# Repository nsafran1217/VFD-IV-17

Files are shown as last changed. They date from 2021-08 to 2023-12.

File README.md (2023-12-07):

# VFD-IV-17
This repository contains an Arduino Library and board design for a 4-tube IV-17 board. These boards are chainable.

Requires a 5V, 2.4V, and 25V power supply.

This board has found a permanent home in my Nixie Weather Clock: https://nsafran.com/nixie-and-vfd-weather-clock.html

Some more info on the use of the boards is on my website: https://nsafran.com/iv17-vfd-board.html

The vfddesigner folder is a quick and dirty c# application to help create the bytes to send for each digit. The exe is in vfddesigner/bin/Debug.





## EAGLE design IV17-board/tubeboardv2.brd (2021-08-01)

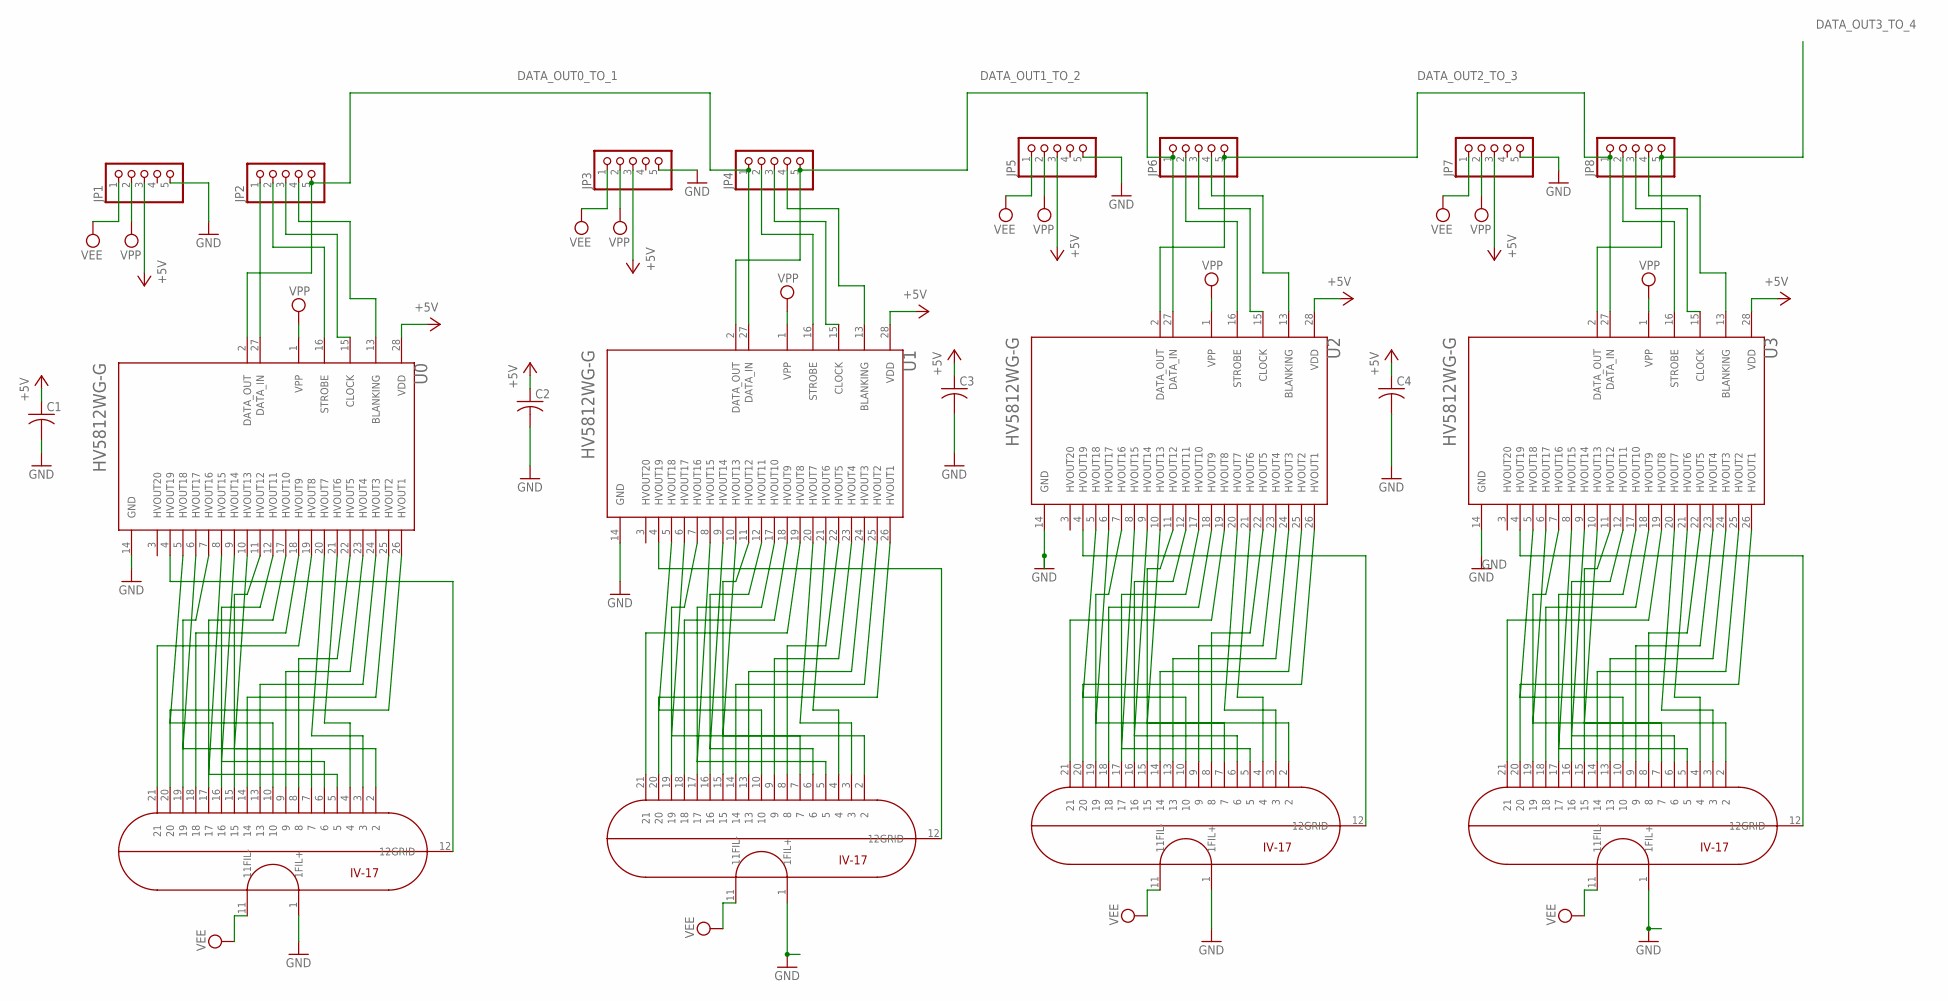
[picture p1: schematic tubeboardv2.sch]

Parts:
C1, C2, C3, C4: C-USC0805; C0805
IV0, IV1, IV2, IV3: IV17; NIXIE-22
JP1, JP2, JP3, JP4, JP5, JP6, JP7, JP8: PINHD-1X5; 1X05
U0, U1, U2, U3: MICROCHIP_HV5812WG-GMICROCHIP_HV5812WG-G_0_0; MICROCHIP_HV5812WG-G_0

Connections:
+5V: C1.1, C2.1, C3.1, C4.1, JP1.3, JP3.3, JP5.3, JP7.3, U0.28 (VDD), U1.28 (VDD), U2.28 (VDD), U3.28 (VDD)
BLANK: JP2.4, JP4.4, JP6.4, JP8.4, U0.13 (BLANKING), U1.13 (BLANKING), U2.13 (BLANKING), U3.13 (BLANKING)
CLOCK: JP2.3, JP4.3, JP6.3, JP8.3, U0.15 (CLOCK), U1.15 (CLOCK), U2.15 (CLOCK), U3.15 (CLOCK)
DATA_IN: JP2.1, U0.27 (DATA_IN)
DATA_OUT0_TO_1: JP2.5, JP4.1, U0.2 (DATA_OUT), U1.27 (DATA_IN)
DATA_OUT1_TO_2: JP4.5, JP6.1, U1.2 (DATA_OUT), U2.27 (DATA_IN)
DATA_OUT2_TO_3: JP6.5, JP8.1, U2.2 (DATA_OUT), U3.27 (DATA_IN)
DATA_OUT3_TO_4: JP8.5, U3.2 (DATA_OUT)
GND: C1.2, C2.2, C3.2, C4.2, IV0.1 (1FIL+), IV1.1 (1FIL+), IV2.1 (1FIL+), IV3.1 (1FIL+), JP1.5, JP3.5, JP5.5, JP7.5, U0.14 (GND), U1.14 (GND), U2.14 (GND), U3.14 (GND)
unnamed: IV0.20, U0.26 (HVOUT1)
unnamed: IV0.14, U0.25 (HVOUT2)
unnamed: IV0.13, U0.24 (HVOUT3)
unnamed: IV0.9, U0.23 (HVOUT4)
unnamed: IV0.8, U0.22 (HVOUT5)
unnamed: IV0.4, U0.21 (HVOUT6)
unnamed: IV0.3, U0.20 (HVOUT7)
unnamed: IV0.21, U0.19 (HVOUT8)
unnamed: IV0.18, U0.18 (HVOUT9)
unnamed: IV0.17, U0.17 (HVOUT10)
unnamed: IV0.16, U0.12 (HVOUT11)
unnamed: IV0.15, U0.11 (HVOUT12)
unnamed: IV0.7, U0.10 (HVOUT13)
unnamed: IV0.6, U0.9 (HVOUT14)
unnamed: IV0.5, U0.8 (HVOUT15)
unnamed: IV0.19, U0.7 (HVOUT16)
unnamed: IV0.2, U0.6 (HVOUT17)
unnamed: IV0.10, U0.5 (HVOUT18)
unnamed: IV0.12 (12GRID), U0.4 (HVOUT19)
unnamed: IV1.20, U1.26 (HVOUT1)
unnamed: IV1.14, U1.25 (HVOUT2)
unnamed: IV1.13, U1.24 (HVOUT3)
unnamed: IV1.9, U1.23 (HVOUT4)
unnamed: IV1.8, U1.22 (HVOUT5)
unnamed: IV1.4, U1.21 (HVOUT6)
unnamed: IV1.3, U1.20 (HVOUT7)
unnamed: IV1.21, U1.19 (HVOUT8)
unnamed: IV1.18, U1.18 (HVOUT9)
unnamed: IV1.17, U1.17 (HVOUT10)
unnamed: IV1.16, U1.12 (HVOUT11)
unnamed: IV1.15, U1.11 (HVOUT12)
unnamed: IV1.7, U1.10 (HVOUT13)
unnamed: IV1.6, U1.9 (HVOUT14)
unnamed: IV1.5, U1.8 (HVOUT15)
unnamed: IV1.19, U1.7 (HVOUT16)
unnamed: IV1.2, U1.6 (HVOUT17)
unnamed: IV1.10, U1.5 (HVOUT18)
unnamed: IV1.12 (12GRID), U1.4 (HVOUT19)
unnamed: IV2.20, U2.26 (HVOUT1)
unnamed: IV2.14, U2.25 (HVOUT2)
unnamed: IV2.13, U2.24 (HVOUT3)
unnamed: IV2.9, U2.23 (HVOUT4)
unnamed: IV2.8, U2.22 (HVOUT5)
unnamed: IV2.4, U2.21 (HVOUT6)
unnamed: IV2.3, U2.20 (HVOUT7)
unnamed: IV2.21, U2.19 (HVOUT8)
unnamed: IV2.18, U2.18 (HVOUT9)
unnamed: IV2.17, U2.17 (HVOUT10)
unnamed: IV2.16, U2.12 (HVOUT11)
unnamed: IV2.15, U2.11 (HVOUT12)
unnamed: IV2.7, U2.10 (HVOUT13)
unnamed: IV2.6, U2.9 (HVOUT14)
unnamed: IV2.5, U2.8 (HVOUT15)
unnamed: IV2.19, U2.7 (HVOUT16)
unnamed: IV2.2, U2.6 (HVOUT17)
unnamed: IV2.10, U2.5 (HVOUT18)
unnamed: IV2.12 (12GRID), U2.4 (HVOUT19)
unnamed: IV3.20, U3.26 (HVOUT1)
unnamed: IV3.14, U3.25 (HVOUT2)
unnamed: IV3.13, U3.24 (HVOUT3)
unnamed: IV3.9, U3.23 (HVOUT4)
unnamed: IV3.8, U3.22 (HVOUT5)
unnamed: IV3.4, U3.21 (HVOUT6)
unnamed: IV3.3, U3.20 (HVOUT7)
unnamed: IV3.21, U3.19 (HVOUT8)
unnamed: IV3.18, U3.18 (HVOUT9)
unnamed: IV3.17, U3.17 (HVOUT10)
unnamed: IV3.16, U3.12 (HVOUT11)
unnamed: IV3.15, U3.11 (HVOUT12)
unnamed: IV3.7, U3.10 (HVOUT13)
unnamed: IV3.6, U3.9 (HVOUT14)
unnamed: IV3.5, U3.8 (HVOUT15)
unnamed: IV3.19, U3.7 (HVOUT16)
unnamed: IV3.2, U3.6 (HVOUT17)
unnamed: IV3.10, U3.5 (HVOUT18)
unnamed: IV3.12 (12GRID), U3.4 (HVOUT19)
STROBE: JP2.2, JP4.2, JP6.2, JP8.2, U0.16 (STROBE), U1.16 (STROBE), U2.16 (STROBE), U3.16 (STROBE)
VEE: IV0.11 (11FIL-), IV1.11 (11FIL-), IV2.11 (11FIL-), IV3.11 (11FIL-), JP1.1, JP3.1, JP5.1, JP7.1
VPP: JP1.2, JP3.2, JP5.2, JP7.2, U0.1 (VPP), U1.1 (VPP), U2.1 (VPP), U3.1 (VPP)

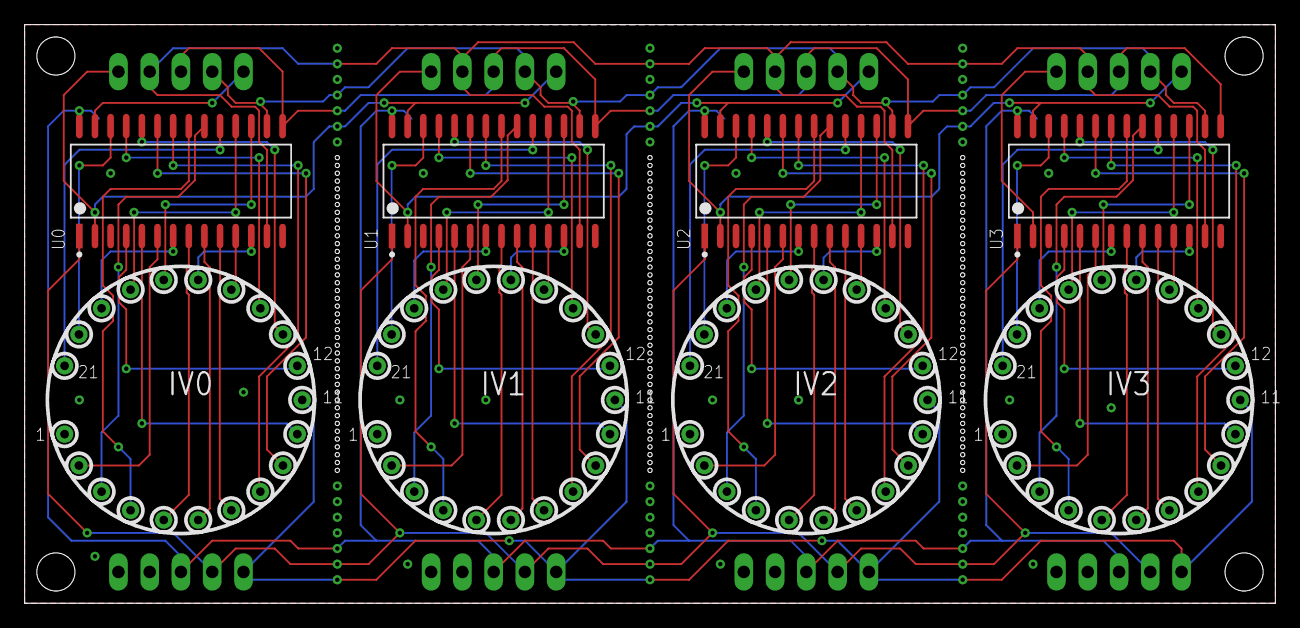
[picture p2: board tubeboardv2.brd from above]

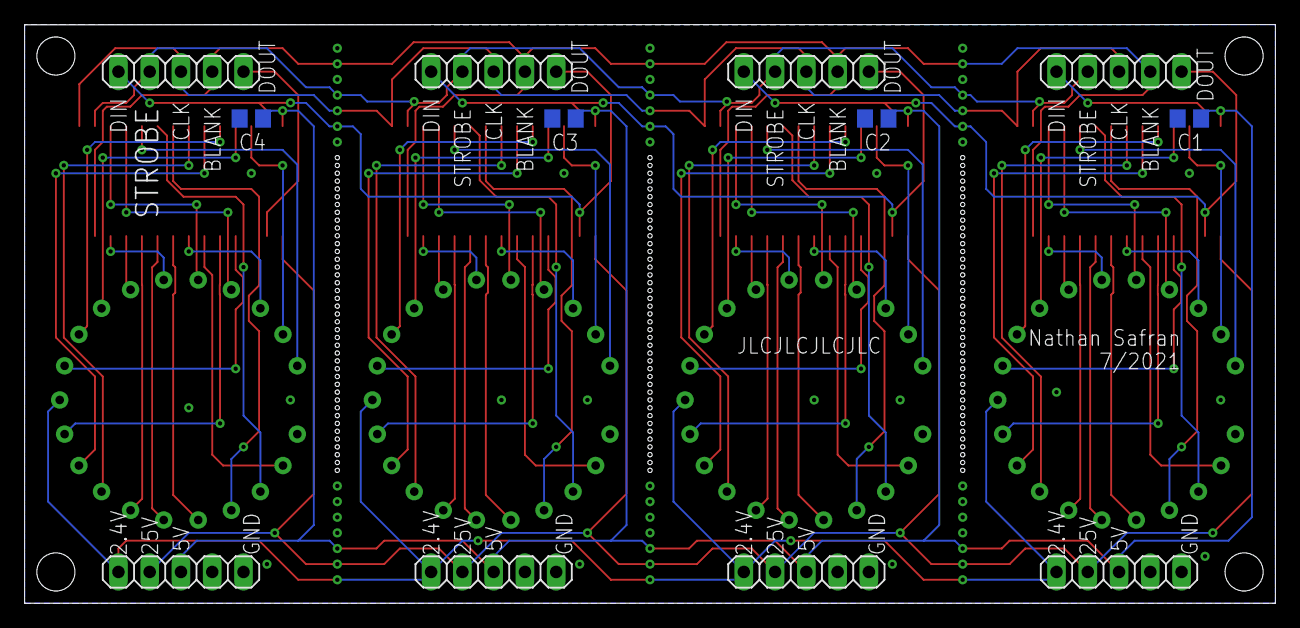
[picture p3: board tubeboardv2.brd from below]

Board: 2 copper layers, 101.6 x 47.0 mm, 20 parts (12 on the bottom side), 88 nets.

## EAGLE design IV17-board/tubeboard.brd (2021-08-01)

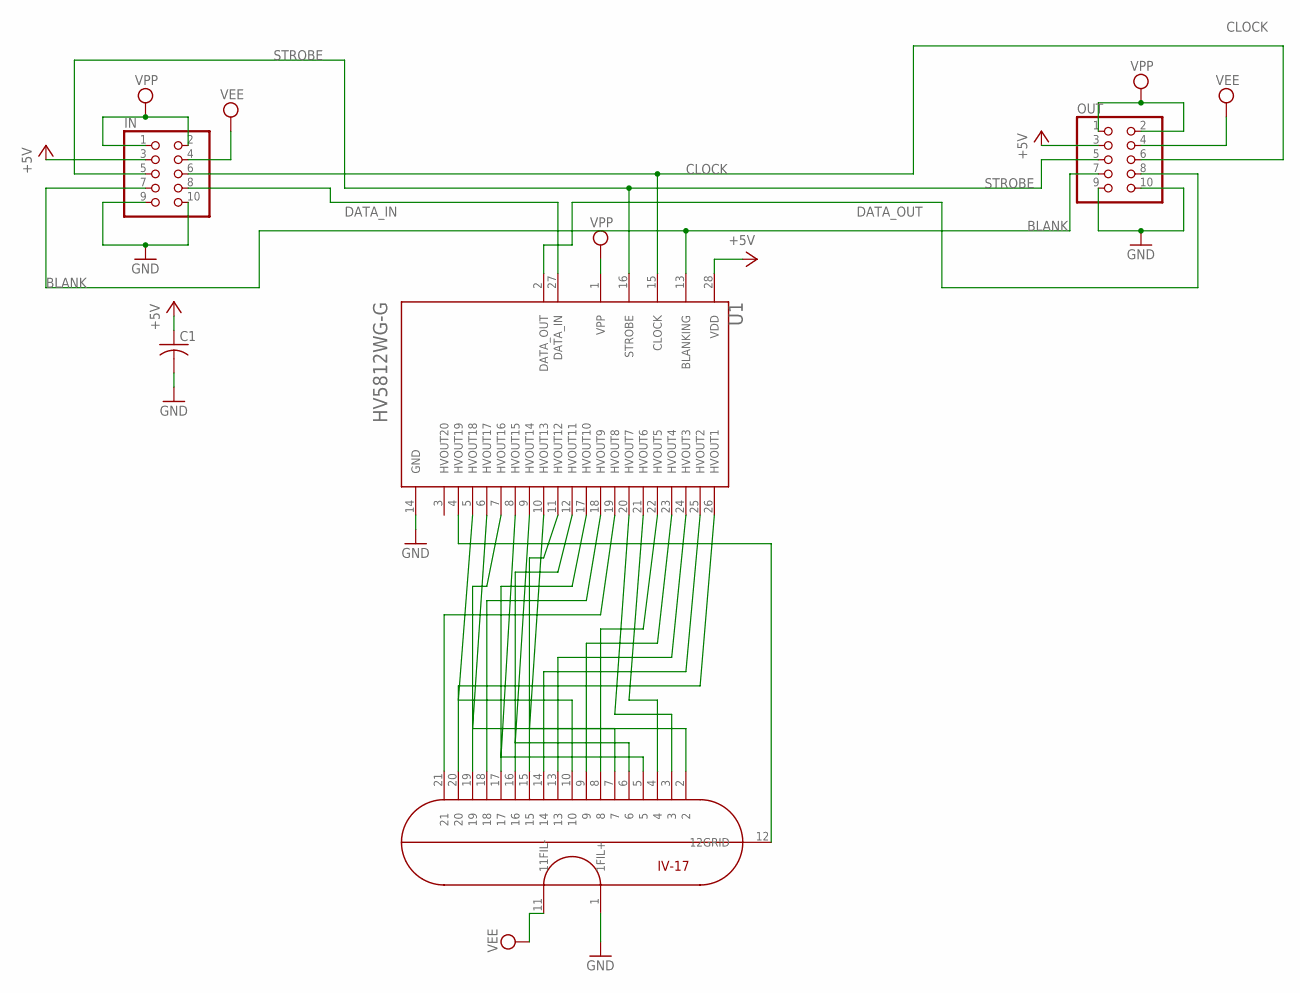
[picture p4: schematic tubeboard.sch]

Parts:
C1: C-USC0805; C0805
IN: PINHD-2X5/90; 2X05/90
IV17: IV17; NIXIE-22
OUT: PINHD-2X5/90; 2X05/90
U1: MICROCHIP_HV5812WG-GMICROCHIP_HV5812WG-G_0_0; MICROCHIP_HV5812WG-G_0

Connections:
+5V: C1.1, IN.3, OUT.3, U1.28 (VDD)
BLANK: IN.7, OUT.7, U1.13 (BLANKING)
CLOCK: IN.6, OUT.6, U1.15 (CLOCK)
DATA_IN: IN.8, U1.27 (DATA_IN)
DATA_OUT: OUT.8, U1.2 (DATA_OUT)
GND: C1.2, IN.9, IN.10, IV17.1 (1FIL+), OUT.9, OUT.10, U1.14 (GND)
unnamed: IV17.20, U1.26 (HVOUT1)
unnamed: IV17.14, U1.25 (HVOUT2)
unnamed: IV17.13, U1.24 (HVOUT3)
unnamed: IV17.9, U1.23 (HVOUT4)
unnamed: IV17.8, U1.22 (HVOUT5)
unnamed: IV17.4, U1.21 (HVOUT6)
unnamed: IV17.3, U1.20 (HVOUT7)
unnamed: IV17.21, U1.19 (HVOUT8)
unnamed: IV17.18, U1.18 (HVOUT9)
unnamed: IV17.17, U1.17 (HVOUT10)
unnamed: IV17.16, U1.12 (HVOUT11)
unnamed: IV17.15, U1.11 (HVOUT12)
unnamed: IV17.7, U1.10 (HVOUT13)
unnamed: IV17.6, U1.9 (HVOUT14)
unnamed: IV17.5, U1.8 (HVOUT15)
unnamed: IV17.19, U1.7 (HVOUT16)
unnamed: IV17.2, U1.6 (HVOUT17)
unnamed: IV17.10, U1.5 (HVOUT18)
unnamed: IV17.12 (12GRID), U1.4 (HVOUT19)
STROBE: IN.5, OUT.5, U1.16 (STROBE)
VEE: IN.4, IV17.11 (11FIL-), OUT.4
VPP: IN.1, IN.2, OUT.1, OUT.2, U1.1 (VPP)

Board: 2 copper layers, 5 parts (2 on the bottom side), 28 nets, no tracks yet.

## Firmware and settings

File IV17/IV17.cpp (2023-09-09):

/*
Library for IV-17 and IV-4 Sixteen segment alphanumeric soviet VFD tube
Nathan Safran - 9/9/2023
*/

#include "Arduino.h"
#include "IV17.h"

IV17::IV17(uint8_t dataPin, uint8_t clockPin, uint8_t latchPin, uint8_t blankPin, uint8_t numOfTubes)
{
    pinMode(dataPin, OUTPUT);
    pinMode(clockPin, OUTPUT);
    pinMode(latchPin, OUTPUT);
    pinMode(blankPin, OUTPUT);
    _dataPin = dataPin;
    _clockPin = clockPin;
    _latchPin = latchPin;
    _blankPin = blankPin;
    _numOfTubes = numOfTubes;
    _timeSinceLastScroll = millis();
    _scrollIndex = 0;
}

void IV17::shiftOutChar(char c, boolean latch)
{
    if (c < 0x80 ){ //check if valid ASCII
        shiftOut20Bits (MSBFIRST, _asciiLookupIV17[c] | _gridPin) ; // always make sure the grid pin is on
    }
    else
    {
        shiftOut20Bits(MSBFIRST, _asciiLookupIV17['?'] | _gridPin);
    }
    if (latch)
    {
        digitalWrite(_latchPin, LOW);
        digitalWrite(_latchPin, HIGH);
    }
}

void IV17::shiftOutCyrillicChar(const char c[], boolean latch)
{
    if (((c[0] & 0xE0) == 0xC0) &&  //check if valid UTF-8 chars that we have in the table
        ((c[1] & 0xC0) == 0x80 &&
         (c[1] < 0xb0)))
    {
        shiftOut20Bits(MSBFIRST, _cyrillicLookupIV17[(c[1] - 0x80)] | _gridPin); // always make sure the grid pin is on
    }
    else
    {
        shiftOut20Bits(MSBFIRST, _asciiLookupIV17['?'] | _gridPin);
    }
    if (latch)
    {
        digitalWrite(_latchPin, LOW);
        digitalWrite(_latchPin, HIGH);
    }
}
void IV17::shiftOutString(String s)
{
    digitalWrite(_latchPin, LOW);

    char cc[3] = {0, 0, 0};
    for (int i = s.length() - 1; i >= 0; i--) // need to do reverse order because hardware shifts in from left to right.
    {
        if (s[i] > 0x80)
        { // UTF-8 char
            cc[0] = s[i - 1];
            cc[1] = s[i];
            i--;
            shiftOutCyrillicChar(cc, false);
        }
        else
        {
            shiftOutChar(s[i], false);
        }
    }
    digitalWrite(_latchPin, HIGH);
}

void IV17::setScrollingString(String s, int delay)
{
    _scrollingString = s;
    _delayToScroll = delay;
    _scrollIndex = 0;
    _spaceIndex = 0;
}

void IV17::scrollStringSync()
{ // synchronous scroll display. AKA blocking until entire string scrolls.
    scrollString();
    while (_scrollIndex <= (_scrollingString.length()) && _scrollIndex != 0)
    {
        scrollString();
    }
}
void IV17::scrollString()
{ // call in main loop for async scroll.

    unsigned long currentMillis = millis();
    if ((currentMillis - _timeSinceLastScroll) > _delayToScroll)
    {
        digitalWrite(_latchPin, LOW);
        int endIndex = _scrollIndex;
        int startIndex = _scrollIndex;
        int charCount = 0;
        String spaces = "";
        if (_spaceIndex <= _numOfTubes)
        {
            for (int i = 0; i < _numOfTubes - _spaceIndex; i++)
            {
                spaces += ' ';
                charCount++;
            }
            _spaceIndex++;
            _scrollIndex = 0;
        }

        while (charCount < _numOfTubes && endIndex < _scrollingString.length())
        {
            if (_scrollingString[endIndex] < 0x80) // ascii
            {
                charCount++;
                endIndex++;
            }
            else
            {
                if (((_scrollingString[endIndex] & 0xE0) == 0xC0) &&
                    (endIndex + 1 < _scrollingString.length()) &&
                    ((_scrollingString[endIndex + 1] & 0xC0) == 0x80 &&
                     (_scrollingString[endIndex + 1] < 0xb0)))
                {
                    charCount++;   // Increment character count
                    endIndex += 2; // Move to the next character
                }
                else
                {
                    // Invalid UTF-8 sequence, skip it
                    endIndex++;
                }
            }
        }

        String substringToDisplay = spaces + _scrollingString.substring(_scrollIndex, endIndex);
        while (charCount < _numOfTubes)
        {
            substringToDisplay += ' '; // Add spaces to fill the remaining characters
            charCount++;
        }
        shiftOutString(substringToDisplay);
        if (_scrollingString[_scrollIndex] == 0xd0)
        {
            _scrollIndex++;
        }
        _scrollIndex++;

        // Reset to the beginning of the string when the end is reached
        if (_scrollIndex >= _scrollingString.length())
        {
            _scrollIndex = 0;
            _spaceIndex = 0;
        }
        digitalWrite(_latchPin, HIGH);
        _timeSinceLastScroll = millis();
    }
}

void IV17::shiftOut20Bits(uint8_t bitOrder, uint32_t val)
{
    uint8_t i;
    for (i = 0; i < 20; i++)
    {
        if (bitOrder == LSBFIRST)
            digitalWrite(_dataPin, !!(val & (1ul << i))); // 1ul tells it to use an unisgned long. If we use just 1, its only 16 bits
        else
            digitalWrite(_dataPin, !!(val & (1ul << (19 - i))));

        digitalWrite(_clockPin, HIGH);
        digitalWrite(_clockPin, LOW);
    }
}

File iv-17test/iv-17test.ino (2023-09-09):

int LATCHPIN = 9;

int CLOCKPIN = 10;

int DATAPIN = 8;
int blank = 11;
int num;
int grid = 1;
unsigned long timeStart = millis();
unsigned long lastTime = 0;
unsigned long j = 0;

const uint32_t asciiLookupIV17[128] = {

0,0,0,0,0,0,0,0,0,0,0,0,0,0,0,0,0,0,0,0,0,0,0,0,0,0,0,0,0,0,0,0,0, 

0b00100000000000001100,  //!
0b00000000001000000100,  //"
0b00001000101000111100,  //#
0b00001010101010111011,  //$
0b00001110111010011001,  //%
0b00001001001101110001,  //&
0b00000000001000000000,  //'
0b00000001010000000000,  //(
0b00000100000100000000,  //)
0b00001111111100000000,  //*
0b00001010101000000000,  //+
0b00000100000000000000,  //,
0b00001000100000000000,  //-
0b00100000000000000000,  //.
0b00000100010000000000,  ///

0b00000100010011111111,  //0
0b00000000010000001100,  //1
0b00001000100001110111,  //2
0b00000000100000111111,  //3
0b00001000100010001100,  //4
0b00001001000010110011,  //5
0b00001000100011111011,  //6
0b00000000000000001111,  //7
0b00001000100011111111,  //8
0b00001000100010111111,  //9
0b00000010001000000000,  //:
0b00000100001000000000,  //;
0b00000001010000000000,  //<
0b00001000100000110000,  //=
0b00000100000100000000,  //>
0b00100010100000000111,  //?
0b00000000101011110111,  //@
0b00001000100011001111,  //A
0b00000010101000111111,  //B
0b00000000000011110011,  //C
0b00000010001000111111,  //D
0b00001000000011110011,  //E
0b00001000000011000011,  //F
0b00000000100011111011,  //G
0b00001000100011001100,  //H
0b00000010001000110011,  //I
0b00000000000001111100,  //J
0b00001001010011000000,  //K
0b00000000000011110000,  //L
0b00000000010111001100,  //M
0b00000001000111001100,  //N
0b00000000000011111111,  //O
0b00001000100011000111,  //P
0b00000001000011111111,  //Q
0b00001001100011000111,  //R
0b00001000100010111011,  //S
0b00000010001000000011,  //T
0b00000000000011111100,  //U
0b00000100010011000000,  //V
0b00000101000011001100,  //W
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

  
  };


void shiftOutChar(char c){
    digitalWrite(LATCHPIN, LOW);
    shiftOut20Bits(DATAPIN, CLOCKPIN, MSBFIRST, asciiLookupIV17[c] | grid); //262144
    digitalWrite(LATCHPIN, HIGH);

}




void setup()
{
    //Start Serial for debuging purposes
    Serial.begin(9600);
    //set pins to output because they are addressed in the main loop
    pinMode(LATCHPIN, OUTPUT);

  pinMode(CLOCKPIN, OUTPUT);
  pinMode(DATAPIN, OUTPUT);
    pinMode(blank, OUTPUT);
    digitalWrite(blank, LOW);

  pinMode(blank, OUTPUT);
//analogWrite(blank, 100);
  for (int i=0;i<82;i++){
  digitalWrite(LATCHPIN, LOW);
      digitalWrite(DATAPIN, LOW);
          digitalWrite(CLOCKPIN, HIGH);
        digitalWrite(CLOCKPIN, LOW); 
        delay(5);
        digitalWrite(LATCHPIN, HIGH);
        Serial.println(i);
}
}
void loop()
{
  uint32_t grid = 0b01000000000000000000;
 


 for (uint16_t i=32 ; i < 127 ; i++){
     
     //shiftOut(DATAPIN, CLOCKPIN, MSBFIRST, startvar); 
  
    digitalWrite(LATCHPIN, LOW);
    shiftOut20Bits(DATAPIN, CLOCKPIN, MSBFIRST, asciiLookupIV17[i] | grid); //262144
    digitalWrite(LATCHPIN, HIGH);
    //Serial.println(startvar);

    delay(500);
}


}


void shiftOut20Bits(uint8_t dataPin, uint8_t clockPin, uint8_t bitOrder, uint32_t val)
{
    uint8_t i;

    for (i = 0; i < 20; i++)  {
        if (bitOrder == LSBFIRST)
            digitalWrite(dataPin, !!(val & (1ul << i)));   //1ul tells it to use an unisgned long. If we use just 1, its only 16 bits
        else    
            digitalWrite(dataPin, !!(val & (1ul << (19 - i))));

        digitalWrite(clockPin, HIGH);
        digitalWrite(clockPin, LOW);        
    }
}

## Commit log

2021-08-01 added designer, EAGLE files, test arduino sketch
    [tubeboard.brd, tubeboard.sch, tubeboardv2.brd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]
2021-08-03 Added library to control tubes easier
2023-06-22 Edit VFD Designer to output different formats
    [tubeboardv2.drl]
